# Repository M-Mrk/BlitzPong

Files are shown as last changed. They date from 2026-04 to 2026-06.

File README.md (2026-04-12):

# BlitzPong

A precision trainer for table tennis that helps develop accuracy and ball placement control.

The device features 2 rows of 5 targets each. Targets illuminate to indicate where to hit, and your score increases with each successful hit.

**Note:** Current version supports individual row training without cross-row communication.
**Note:** Current hardware is wrong due to lcsc/Xinglight component change (see end). Do not try to build before this is addressed

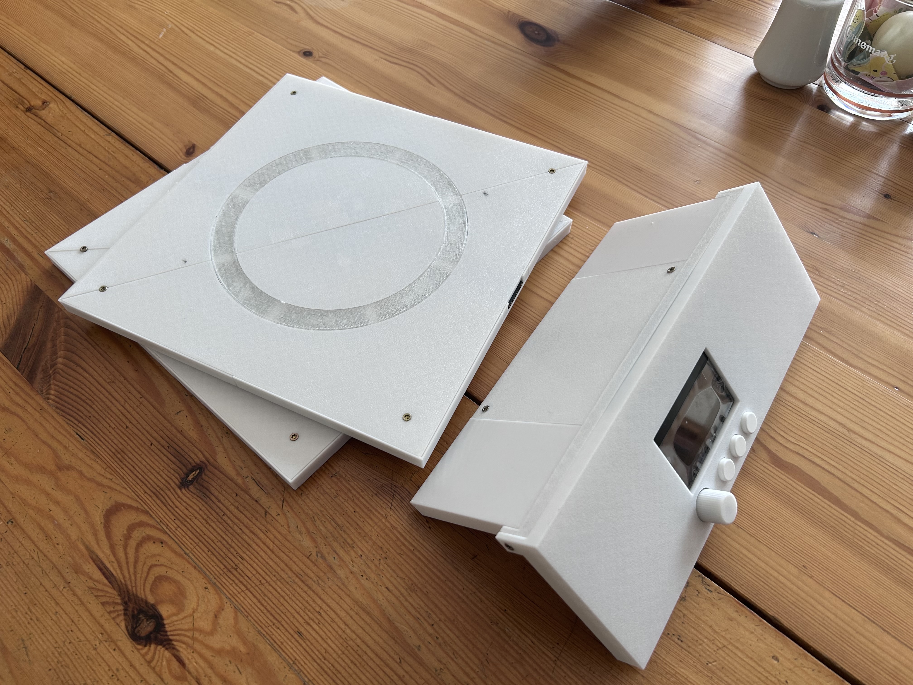
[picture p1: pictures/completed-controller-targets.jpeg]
Completed Assembly


## Use Case
Many table tennis players only focus on spin and speed, but neglect conscious placement to specific table zones. BlitzPong trains exactly that - precision targeting and shot placement.
Just place all the targets on the table, put the controller on the side, go through the setup and start the game.

## Why I made this
I noticed exactly what is mentioned above and was participating in [Hackclub's Blueprint](https://blueprint.hackclub.com) so I took the opportunity to build something for training precision or at least conscious.

# Pictures and Assembly
## Target
### PCB
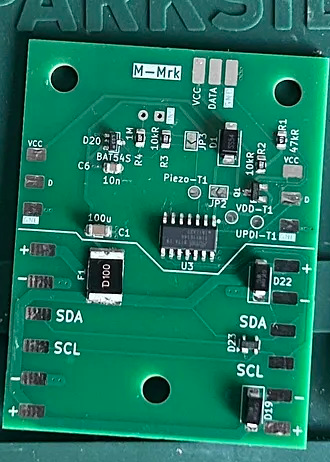
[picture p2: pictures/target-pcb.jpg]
Target PCB

- Place all components and solder
- Solder on piezo disc. Make sure to connect the bigger disc to the rounded pad
- Put isolating tape on the piezo disc on the side with the small disc
- Connect UPDI Serial tool and open [this](Software/target/platformio.ini) in PlatformIO and upload

### Case
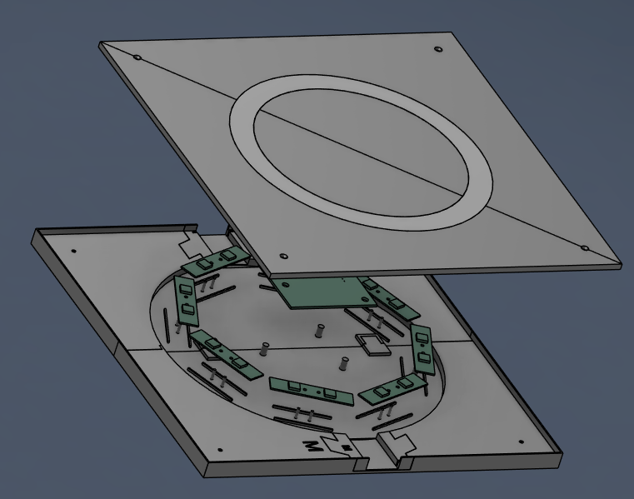
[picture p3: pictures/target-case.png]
Target Case

- Print everything in PETG and the diffuser ring preferably in transparent PETG
- Push both bottom parts together
- Place all 8 LED pcbs and the target pcb
- Connect the LED pcbs with wires like [shown here](pictures/target-led-diagram.png)
- Solder wires to one female pogo connector and one male connector. (Watch out for the magnets!)
- Put pogo connectors into the cutouts and solder wires to target pcb ([diagram](pictures/target-pogo-diagram.png)). (Orient red mark of connector to where the M/F indent is and put female pogo connector in F cutout and vice versa)
- Slide both top parts together and press fit the diffuser
- Glue the piezo disc in the center of the bottom of the top parts
- Press top cover on and screw all 4 2.5x10mm screws in

## Controller
### PCB
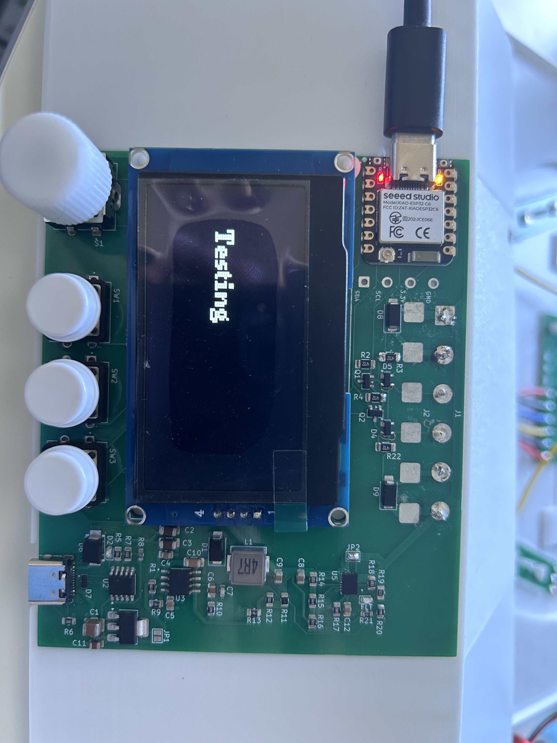
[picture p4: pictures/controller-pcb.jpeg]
Controller PCB

**Note:** You may skip the eFuse and its passives. The picture also jumped (JP2) the eFuse, as it can be very hard to solder
- Place all SMD components and solder
- Print display adapter and place
- Place Display, Switches and Encoder and solder. Note that the encoder tabs might be very hard to solder as they are only designed to be wave soldered.
- Put on encoder cap and button caps

### Case
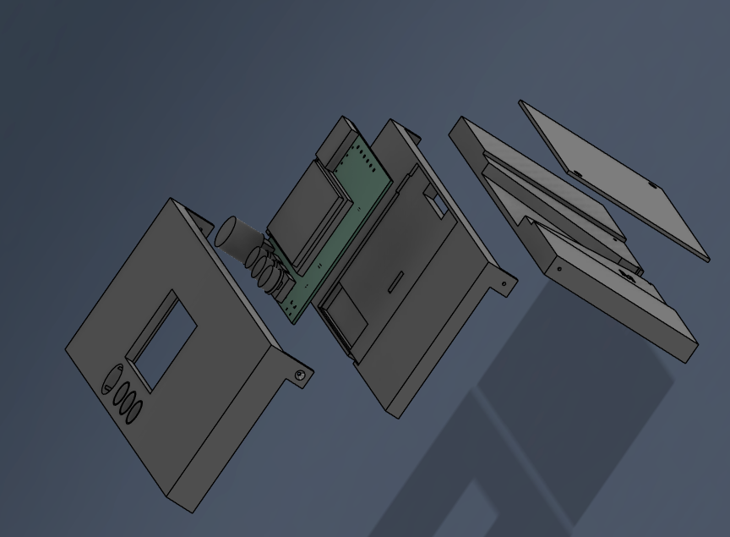
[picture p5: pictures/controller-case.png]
Controller Case

- Print everything
- Solder wires to male pogo connector and place connector in back piece (Put red marked side to where the M indent is)
- Place PCB in center part
- Feed wires through the back of pcb, trim and solder
- Screw on lid to back piece (2.5x10mm Screws)
- Connect MCU to computer, open [this](Software/controller/platformio.ini) in platformIO and upload 
- Press front cover on and screw all 3 pieces together with 2 screws on the side

# BOM
**Note:** The pogo connectors are from RTLECS with 6 Pins, Ears and straight pins
## Controller
|Reference |Qty|Value |Datasheet |LCSC |Link |
|---|---|---|---|---|---|
|C1 |1  |22u |~ |C309062  | |
|C10 |1  |100n |~ |C93194 | |
|C11 |1  |10u |~ |C3039694 | |
|C12 |1  |22n |~ |C1729 | |
|C2,C3 |2  |4.7u |~ |C51205 | |
|C4,C5 |2  |10n |~ |C83170 | |
|C6 |1  |2.2n |~ |C36576 | |
|C7 |1  |22p |~ |C2169931 | |
|C8,C9 |2  |47u |~ |C16780 | |
|D1 |1  |SS54 |~ |C20609300| |
|D2 |1  |LED |~ |C51933292| |
|D3 |1  |PWR_FLT |~ |C51933292| |
|D4,D5 |2  |PRTR5V0U2X |https://assets.nexperia.com/documents/data-sheet/PRTR5V0U2X.pdf |C5180302 | |
|D6 |1  |~ |https://item.szlcsc.com/datasheet/SMBJ24CA/975605.html |C908853  | |
|D7 |1  |~ |https://www.ti.com/cn/lit/gpn/tpd4e05u06 |C138714  | |
|D8,D9 |2  |SMAJ6.0CA |https://www.littelfuse.com/media?itemid=75e32973-b177-4ee3-a0ff-cedaf1abdb93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|C908810  | |
|J2 |1  |Pogo_01x06_male |~ | |https://aliexpress.com/item/1005005284441979.html|
|J3 |1  |G-Switch GT-USB-7010ASV|https://www.usb.org/sites/default/files/documents/usb_type-c.zip |C2988369 | |
|J5 |1  |0.91 OLED |~ |C5248081 ||
|L1 |1  |4.7u |https://www.lcsc.com/datasheet/C5307631.pdf |C5307631 ||
|LCD1 |1  |2.42 OLED |https://atta.szlcsc.com/upload/public/pdf/source/20230720/72FFD800C7ED95A3980F98F3DF4670E2.pdf |C7466001 ||
|Q1,Q2 |2  |BSS138 |https://www.onsemi.com/pub/Collateral/BSS138-D.PDF |C40912 ||
|R1 |1  |665k |~ |C48533721||
|R10 |1  |37.4k |~ |C2999586 ||
|R11 |1  |51.1 |~ |C2077153 ||
|R12 |1  |10.2k |~ |C2933282 ||
|R13 |1  |1.96k |~ |C2930163 ||
|R14,R18 |2  |120k |~ |C17436 ||
|R15 |1  |6.49k |~ |C2933484 ||
|R16 |1  |26.7k |~ |C2999467 ||
|R17 |1  |20k |~ |C2907240 ||
|R19 |1  |42.2k |~ |C5119971 ||
|R2,R3,R4,R22|4  |4.7K |~ |C2907499 ||
|R20 |1  |8.66k |~ |C2933506 ||
|R21 |1  |150 |~ |C2907103 ||
|R5 |1  |24K |~ |C2907246 ||
|R6 |1  |10 |~ |C17415 ||
|R7 |1  |10K |~ |C84376 ||
|R8 |1  |68 |~ |C27592 ||
|R9 |1  |130k |~ |C2933305 ||
|S1 |1  |PEC12R-4120F-S0012 |https://www.lcsc.com/datasheet/C143801.pdf |C143801  ||
|SW1,SW2,SW3 |3  |B3F-4055 |~ |C36498965||
|U1 |1  |XIAO-ESP32-C6-SMD | | |https://aliexpress.com/item/1005010618607905.html|
|U2 |1  |CH224K |https://www.wch.cn/downloads/file/301.html |C970725  ||
|U3 |1  |TPS54531DDAR |https://www.lcsc.com/datasheet/C50605.pdf |C50605 ||
|U4 |1  |AMS1117-3.3 |http://www.advanced-monolithic.com/pdf/ds1117.pdf |C347222  ||
|U5 |1  |TPS25942ARVCR | |C181295  ||
| |4  |Screw 2,5x10mm |~ | |https://www.ebay.de/itm/127200989742|

## Target (with LEDs)
|Reference |Qty|Value |Datasheet |LCSC |Link |
|---|---|---|---|---|---|
|C1 |1  |100u |~ |C15008 | |
|C2,C3,C4,C5 |4  |100nC |~ |C93194 | |
|C6 |1  |10n |~ |C83170 | |
|D1 |1  |SS54 |~ |C20609300| |
|D2,D3,D4,D5,D6,D7,D8,D9,D10,D11,D12,D13,D14,D15,D16,D17|16 |XL-5050RGBC-SK6812B |https://cdn-shop.adafruit.com/product-files/1138/SK6812+LED+datasheet+.pdf |C5349959 | |
|D18,D21 |2  |PRTR5V0U2X |https://assets.nexperia.com/documents/data-sheet/PRTR5V0U2X.pdf |C5180302 | |
|D19,D22 |2  |SMAJ6.0CA |https://www.littelfuse.com/media?itemid=75e32973-b177-4ee3-a0ff-cedaf1abdb93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|C908810  | |
|D20 |1  |BAT54S |https://www.diodes.com/assets/Datasheets/ds11005.pdf |C19726 | |
|F1 |1  |Polyfuse IT2A |~ |C22366130| |
|J1 |1  |Pogo_01x06_female |~ | |https://aliexpress.com/item/1005005284441979.html|
|J2 |1  |Pogo_01x06_male |~ | |https://aliexpress.com/item/1005005284441979.html|
|J5 |1  |Piezo |~ | |https://aliexpress.com/item/1005003133740770.html|
|Q1 |1  |SI2333CDS-HXY | |C18198389| |
|R1 |1  |47kR |~ |C2907330 | |
|R2,R3 |2  |10kR |~ |C84376 | |
|R4 |1  |1M |~ |C17514 | |
|U1 |1  |Attiny1614-SSF |https://www.lcsc.com/datasheet/C614831.pdf |C614831  | |
| |4  |Screw 2,5x10mm |~ | |https://www.ebay.de/itm/127200989742|

# Problems
I designed with 'XINGLIGHT XL-5050RGBC-SK6812B' LEDs in mind and they had the LCSC Number C5349959. I downloaded the datasheet, which you can view [here](misc/old-datasheet.pdf). As seen in the datasheet they work from 3.5 to 5.5 Volts and two of their pins are NC/Not connected. After ordering and soldering I couldn't get them to work reliably and so I redownloaded the datasheet. This [new datasheet](misc/new-datasheet.pdf) exclaims that they work with 9 to 14 Volt and all pins are populated and the order changed. What happend? When viewing the [JLCPCB component Library](https://jlcpcb.com/partdetail/XINGLIGHT-XL_5050RGBCSK6812B/C5349959) which only gets updated when the JLCPCB warehouse runs out of that part it still links the old datasheet and the same LCSC number C5349959. This means that between downloading the datasheet and ordering Xinglight replaced their XL-5050RGBC-SK6812B with a new model running at a completely different volatage and a different pin out, whilst keeping the same name and lcsc number. For now it is a miracle that they even work with just 5 Volt and light up with the wrong pinout, but they often don't turn off or correctly change color and are limited to single channel colors (so only red, green and blue).

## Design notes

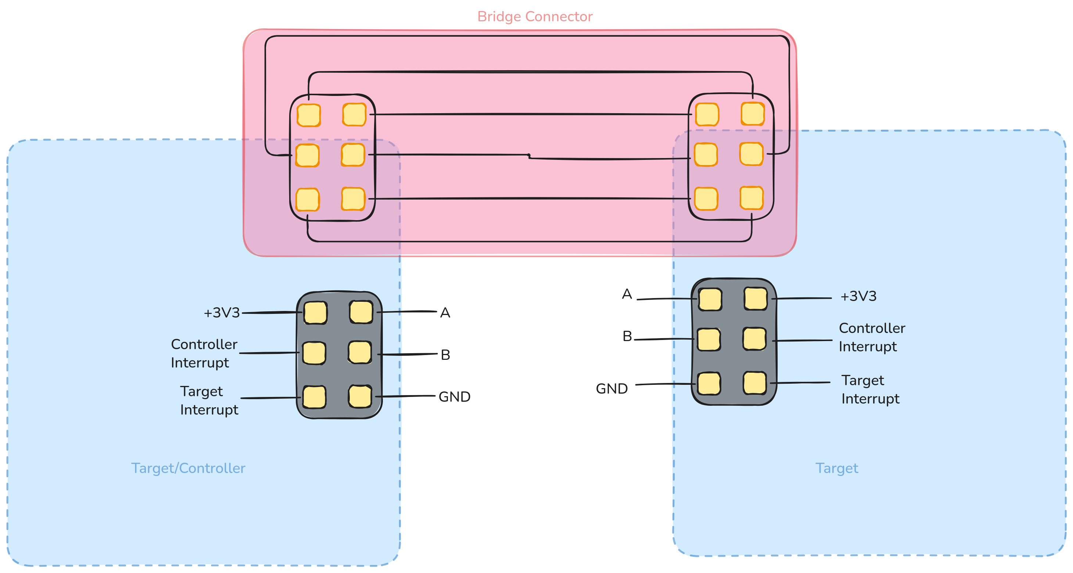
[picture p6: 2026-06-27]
pcb/connector-pinout.png

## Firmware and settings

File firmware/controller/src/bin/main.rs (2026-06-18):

#![no_std]
#![no_main]
#![deny(
    clippy::mem_forget,
    reason = "mem::forget is generally not safe to do with esp_hal types, especially those \
    holding buffers for the duration of a data transfer."
)]
#![deny(clippy::large_stack_frames)]

use defmt::info;
use embassy_executor::Spawner;
use embassy_time::{Duration, Timer};
use esp_backtrace as _;
use esp_hal::clock::CpuClock;
use esp_hal::timer::timg::TimerGroup;
use esp_println as _;

extern crate alloc;

// This creates a default app-descriptor required by the esp-idf bootloader.
// For more information see: <https://docs.espressif.com/projects/esp-idf/en/stable/esp32/api-reference/system/app_image_format.html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>
esp_bootloader_esp_idf::esp_app_desc!();

#[allow(
    clippy::large_stack_frames,
    reason = "it's not unusual to allocate larger buffers etc. in main"
)]
#[esp_rtos::main]
async fn main(spawner: Spawner) -> ! {
    // generator version: 1.3.0
    // generator parameters: --chip esp32c6 -o esp32c6-wroom-1 -o unstable-hal -o alloc -o embassy -o defmt -o esp-backtrace -o neovim -o vscode

    let config = esp_hal::Config::default().with_cpu_clock(CpuClock::max());
    let peripherals = esp_hal::init(config);

    // The following pins are used to bootstrap the chip. They are available
    // for use, but check the datasheet of the module for more information on them.
    // - GPIO4
    // - GPIO5
    // - GPIO8
    // - GPIO9
    // - GPIO15
    // These GPIO pins are in use by some feature of the module and should not be used.
    let _ = peripherals.GPIO24;
    let _ = peripherals.GPIO25;
    let _ = peripherals.GPIO26;
    let _ = peripherals.GPIO27;
    let _ = peripherals.GPIO28;
    let _ = peripherals.GPIO29;
    let _ = peripherals.GPIO30;

    esp_alloc::heap_allocator!(#[esp_hal::ram(reclaimed)] size: 65536);

    let timg0 = TimerGroup::new(peripherals.TIMG0);
    let sw_interrupt =
        esp_hal::interrupt::software::SoftwareInterruptControl::new(peripherals.SW_INTERRUPT);
    esp_rtos::start(timg0.timer0, sw_interrupt.software_interrupt0);

    info!("Embassy initialized!");

    // TODO: Spawn some tasks
    let _ = spawner;

    loop {
        info!("Hello world!");
        Timer::after(Duration::from_secs(1)).await;
    }

    // for inspiration have a look at the examples at https://github.com/esp-rs/esp-hal/tree/esp-hal-v1.1.0/examples
}

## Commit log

2025-10-24 added prototype code for testing piezo and hardware section in README
    [module.kicad_pcb, module.kicad_sch]
2025-10-24 first iteration of the target schematic (w/o updi connector)
    [led_circle.kicad_sch, module.kicad_sch, piezo_sensor.kicad_sch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]
2025-11-14 added updi connector
    [led_circle.kicad_sch, piezo_sensor.kicad_sch, target.kicad_sch]
2025-11-22 fixed some footprint issues
    [led.kicad_sch, led_cap.kicad_sch, led_circle.kicad_sch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]
2025-11-22 pcb of target except aligning for manufacturing
    [target.kicad_pcb]
2025-11-24 finishing up target pcb
    [led.kicad_sch, led_cap.kicad_sch, led_circle.kicad_sch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]
2025-11-28 base schematic for the controller excluding buck
    [PEC12R-4120F-S0012.step, TPS54531DDAR.step, controller.kicad_pcb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]
2025-11-28 cleaned up
    [controller.kicad_sch, level_shifter.kicad_sch, power_input.kicad_sch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]
2025-11-29 implemented PD, buck and LDO for Power Input
    [controller.kicad_sch, power_input.kicad_sch]
2025-12-06 impl eFuse
    [TPS25942ARVCR.step, buck.kicad_sch, controller.kicad_sch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]
2025-12-08 retraced target pcb
    [B3F-4055.step, bom_legacy.csv, buck.kicad_sch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]
2025-12-11 added lcsc numbers to all components and added ESD protection
    [bom_legacy.csv, buck.kicad_sch, controller.csv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]
2025-12-13 redid target pcb with new components
    [esd_power.kicad_sch, target.kicad_pcb]
2025-12-13 did led circle pcb and added 3d models for the controller pcb
    [XIAO-ESP32C6-SMD.step, controller.kicad_sch, led circle.csv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]
2025-12-13 traced power components on controller pcb and started with the other components (restored from backup)
    [controller.kicad_pcb]
2025-12-14 traced controller pcb and renamed to Blitzpong
    [controller.kicad_pcb, controller.kicad_sch]
2025-12-15 finished all pcbs by adjusting traces acording to 1oz copper weight
    [controller-B_Cu.gbl, controller-B_Mask.gbs, controller-B_Paste.gbp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]
2025-12-16 exported all pcbs
    [controller-B_Cu.gbl, controller-B_Mask.gbs, controller-B_Paste.gbp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]
2026-01-27 fixed error in BOM missing LCSC number
    [controller.csv]
2026-02-14 Switched to attiny1614 and fixed esd for the i2c lines (target pcb)
    [esd.kicad_sch, target.csv, target.kicad_pcb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]
2026-02-14 exported and adjusted target pcb
    [Target_bom.csv, Target_designators.csv, Target_positions.csv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]
2026-03-07 Added software for i2c-master tester and test target functionallity
2026-04-12 Updated README, removed Embedded folder, moved BOMs to root
    [bom.csv, controller-back.stp, controller-center.stp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]
2026-04-12 Added information about Xinglight replacement, added step files and fixed readme errors
    [controller-full-assembly.stp, controller.csv, rotaryKnobencoder_cap.stl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]
2026-06-18 Initial commit for v2
    [B3F-4055.step, PEC12R-4120F-S0012.step, TPS25942ARVCR.step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]
2026-06-19 Target: Added stm32 and connectors to schematic
    [leds.kicad_sch, target.kicad_sch]
2026-06-20 First iteration of target schematic
    [leds.kicad_sch, target.kicad_sch]
2026-06-27 Started controller schematic
    [controller.kicad_sch, leds.kicad_sch, power.kicad_sch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]
2026-06-27 Added buzzer and connector to controller schematic
    [controller.kicad_sch]
